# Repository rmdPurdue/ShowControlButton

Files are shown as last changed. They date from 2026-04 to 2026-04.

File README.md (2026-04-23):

# ShowControlButton
ShowControlButton is a simple, single-pushbutton controller in a box. Inside the box: a Feather M4 Express microcontroller, a relay breakout, an Ethernet breakout, and the capability to put a single pushbutton in your entertainment project and have it trigger a contact closure or trigger the contact closure and send a configurable OSC message to your show network.
## Easy to use
If you don't need OSC capabilities, set up is simple: supply power to the box using the Micro USB port on the back of the box, insert a 1/4" TS plug into the contact closure port and connect the other end to your footswitch device, MIDI footswitch controller, PLC input, or other device with a sourcing discrete input, up to 24V DC. BAM! Press the button, the contact closes for five seconds. Bonus: the 10mm diffused blue LED lights up when the contact is closed.

If you want OSC capabilities, the set up takes a few extra steps. You'll need to configure the network interface for your network, then configure the outgoing OSC message. Push the button: OSC message sent **and** contact closed!
## Network Configuration
The default network configuration for the ShowControlButton:

|Field|Setting|
|---|---|
|IP Address|192.168.1.100|
|Subnet Mask|255.255.255.0|
|Gateway|192.168.1.1|
|DNS Server|8.8.8.8|

To change the network settins for the ShowControlButton, connect the device to your laptop or computer with an Ethernet cable using the Ethernet port on the back of the box. Once connected, supply power using the Micro USB port on the back of the box. Ensure that the network interface on your laptop or computer is in the same address range and is using the same subnet mask as the ShowControl Button. Open a web browser and point it to the IP address of the ShowControlButton at port 5000 (e.g. http://192.168.1.100:5000).

> [!IMPORTANT]
> As of this writing, the ShowControlButton only detects a network connection at power up. If it is not connected to a network at power up, it will shut down the network interface and it will not detect the presence of a network later, even if one is connected, until power has been removed and resupplied. Future versions of the firmware should address this issue.

> [!TIP]
> "Uh oh! I changed my network settings at some point and I don't remember them. How do I access the network configuration web page?!" Easy: press and hold the reset button (located inside the small hole on the bottom of the box) for at least five seconds. This should restore the network configuration settings to the default settings. Connect your network cable, supply power, and point your web browser to http://192.168.1.100:5000 and you should be good to go!

## OSC Set up
Configuring the settings for the OSC message you wish to send when the ShowControlButton is pressed is as simple as navigating to the IP address of the device, just as when configuring the network settings. In the second form on the configuration page, you can set the message's destination IP address, the destination port, and the OSC message itself. As with any OSC message, use a blank space to separate any arguments from the address/method and from each other; the code will determine automatically if the argument is an integer, float, or string. Though we have not tested for large numbers of arguments, theoretically you should be able to store quite a few!

> [!IMPORTANT]
> The firmware will interpret any decimal value as a float: "1" is an integer, but "1.0" is a float. If the argument type **must** be an integer, don't include a ".0".

## Troubleshooting ##
The ShowControlButton software has not undergone robust stress testing; typically, if something goes wrong, remove power, count to ten, resupply power then try again. Restore to faculty defaults and reset your network configuration and OSC message configuration, if necessary.

## Parts List ##
- Adafruit Feather M4 Express (https://www.adafruit.com/product/3857)
- Adafruit Relay (Non-latching) Featherwing (https://www.adafruit.com/product/2895)
- Adafruit Ethernet Featherwing (https://www.adafruit.com/product/3201)
- 10mm Diffused Blue LED (https://www.adafruit.com/product/847)
- 10mm LED Bevel LED Holder (https://www.adafruit.com/product/2171)
- 12mm Tactile button (https://www.adafruit.com/product/1119)
- 22mm Plastic Button (white) (https://www.automationdirect.com/adc/shopping/catalog/pushbuttons_-z-_switches_-z-_indicators/pushbuttons/gcx3105)
- Micro USB extension (https://www.digikey.com/en/products/detail/adafruit-industries-llc/6068/25897272)
- Ethernet Coupler (https://www.mcmaster.com/catalog/3243T1)
- 1/4" TS Audio Jack (https://www.mcmaster.com/catalog/1760N21)
- Tactile Button mounting plate (3d printed) (https://github.com/rmdPurdue/ShowControlButton/blob/main/support%20files/Tactile%2BButton%2BMount.stp)
- Enclosure (including feet and standoffs, laser cut from 6mm draftboard) (https://github.com/rmdPurdue/ShowControlButton/tree/main/support%20files/laser-cut)

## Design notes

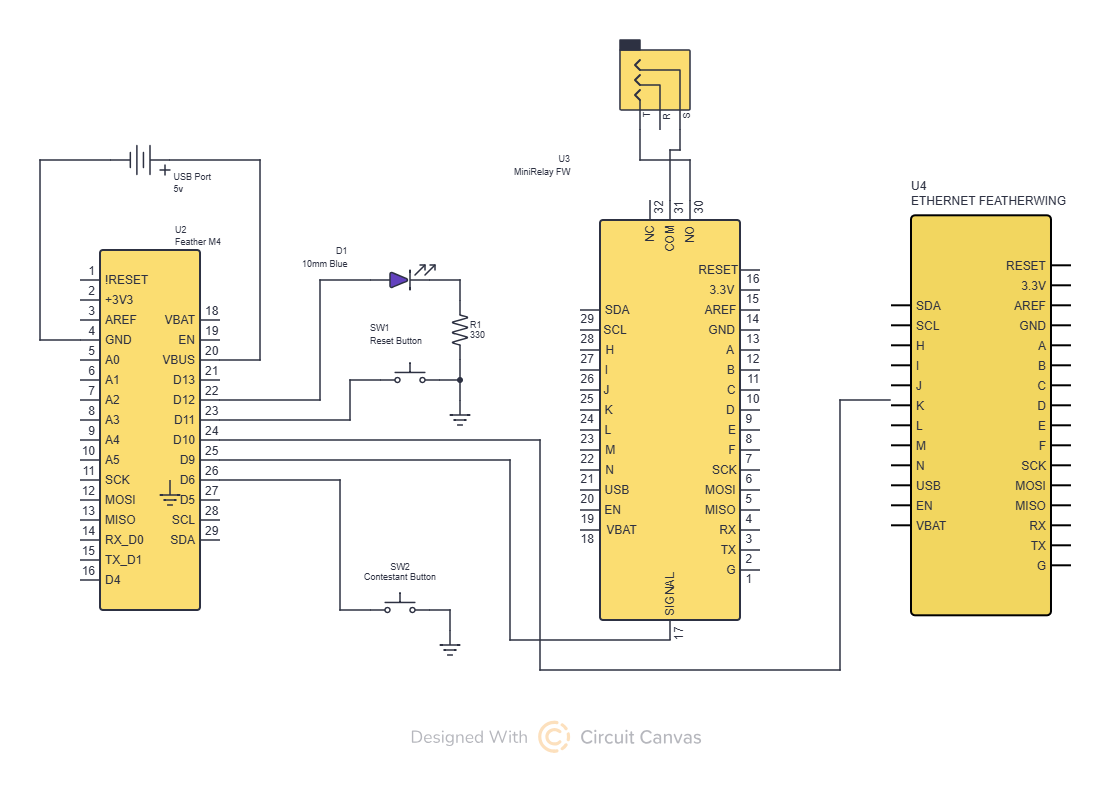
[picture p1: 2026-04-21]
support files/ShowControlButton-schematic.png

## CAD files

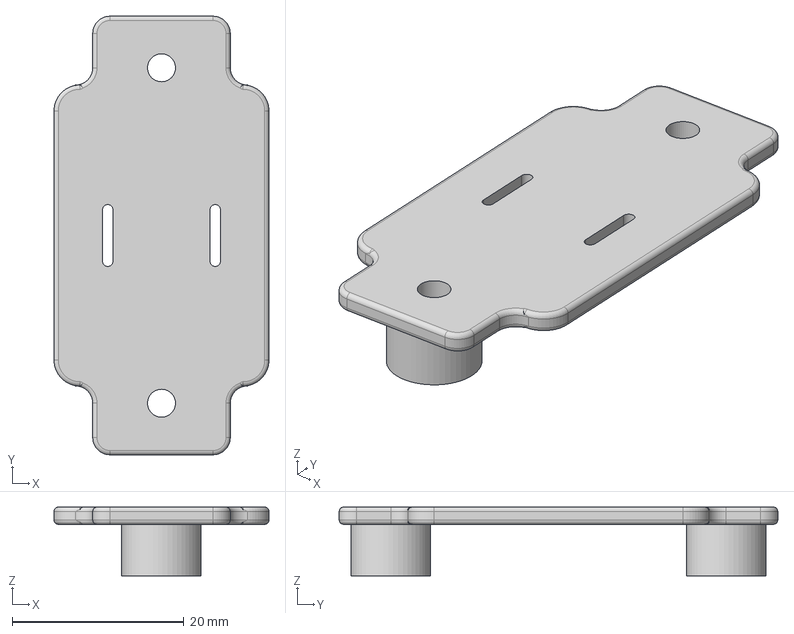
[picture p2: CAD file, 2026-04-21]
support files/Tactile+Button+Mount.stp
25.0 x 51.0 x 8.00 mm

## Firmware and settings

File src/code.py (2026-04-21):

import gc
import os

import adafruit_connection_manager
import board
import digitalio
import time
import microosc

from asyncio import create_task, gather, run
from asyncio import sleep as async_sleep
from adafruit_debouncer import Debouncer
from adafruit_wiznet5k.adafruit_wiznet5k import WIZNET5K

from adafruit_httpserver import (
    MIMETypes,
    POST,
    Response,
    REQUEST_HANDLED_RESPONSE_SENT,
    Request,
    Server,
)

from html import HTML_FORM
from network_config import NetworkConfig
from osc_message import OSCMessage

# Initialize contestant button
button_pin = digitalio.DigitalInOut(board.D6)
button_pin.direction = digitalio.Direction.INPUT
button_pin.pull = digitalio.Pull.UP
button = Debouncer(button_pin, interval=0.01)

# Initialize reset button
reset_pin = digitalio.DigitalInOut(board.D11)
reset_pin.direction = digitalio.Direction.INPUT
reset_pin.pull = digitalio.Pull.UP
reset = Debouncer(reset_pin, interval=0.01)

# Initialize contact closure output
contact = digitalio.DigitalInOut(board.D9)
contact.direction = digitalio.Direction.OUTPUT

# Initialize contact closure reset output for non-latching relay
contact_reset = digitalio.DigitalInOut(board.D13)
contact_reset.direction = digitalio.Direction.OUTPUT

# Initialize local led
led = digitalio.DigitalInOut(board.D12)
led.direction = digitalio.Direction.OUTPUT

# Default network config
my_network_config = NetworkConfig()
my_network_config.ip = os.getenv("IP")
my_network_config.subnet = os.getenv("SN")
my_network_config.gateway = os.getenv("GW")
my_network_config.dns = os.getenv("DNS")

# Initialize OSC message variable
osc_message = OSCMessage()
osc_message.destination = os.getenv("DIP")
osc_message.port = os.getenv("DP")
osc_message.payload(os.getenv("DM"))
if os.getenv("EN") == "True":
    osc_message.state = True
elif os.getenv("EN") == "False":
    osc_message.state = False

# For Adafruit Ethernet FeatherWing
cs = digitalio.DigitalInOut(board.D10)
spi_bus = board.SPI()

# Initialize ethernet interface without DHCP
eth = WIZNET5K(spi_bus, cs, is_dhcp=False)

eth.ifconfig = (my_network_config.ip,
                my_network_config.subnet,
                my_network_config.gateway,
                my_network_config.dns)

MIMETypes.configure(
    default_to="text/plain",
    keep_for=[".html", ".css", ".js", ".png", ".jpg", ".jpeg", ".gif", ".ico"],
)

# Create a socket pool
pool = adafruit_connection_manager.get_radio_socketpool(eth)
server = Server(pool, "../static", debug=True)


@server.route("/")
def base(request: Request):
    checked_state = None
    if osc_message.state:
        checked_state = "checked"
    return Response(request,
                    HTML_FORM.format(
                        network="display:none;",
                        osc="display:none;",
                        checked=checked_state,
                        ip=my_network_config.ip_as_string(),
                        subnet=my_network_config.subnet_as_string(),
                        gateway=my_network_config.gateway_as_string(),
                        dns=my_network_config.dns_as_string(),
                        destinationIP=osc_message.destination,
                        destinationPort=osc_message.port,
                        message=osc_message.payload_no_types()
                    ),
                    content_type="text/html", )


@server.route("/submit-network", POST)
def submit_form_handler(request: Request):
    # Parse form data from the POST request
    form_data = request.form_data
    my_network_config.ip = form_data.get("ip")
    my_network_config.subnet = form_data.get("subnet")
    my_network_config.gateway = form_data.get("gateway")
    my_network_config.dns = form_data.get("dns")
    checked_state = None
    if osc_message.state:
        checked_state = "checked"
    update_toml()
    gc.collect()
    # We have to restart the network connection here!

    return Response(request,
                    HTML_FORM.format(
                        network="display:inline;",
                        osc="display:none;",
                        checked=checked_state,
                        ip=my_network_config.ip_as_string(),
                        subnet=my_network_config.subnet_as_string(),
                        gateway=my_network_config.gateway_as_string(),
                        dns=my_network_config.dns_as_string(),
                        destinationIP=osc_message.destination,
                        destinationPort=osc_message.port,
                        message=osc_message.payload_no_types()
                    ),
                    content_type="text/html", )


@server.route("/submit-osc", POST)
def submit_form_handler(request: Request):
    # Parse form data from the POST request
    form_data = request.form_data
    osc_message.destination = form_data.get("destIp")
    osc_message.port = form_data.get("destPort")
    osc_message.payload(form_data.get("message"))
    if form_data.get("sendOSC") == "on":
        osc_message.state = True
    else:
        osc_message.state = False
    checked_state = None
    if osc_message.state:
        checked_state = "checked"
    update_toml()
    gc.collect()

    return Response(request,
                    HTML_FORM.format(
                        network="display:none;",
                        osc="display:inline;",
                        checked=checked_state,
                        ip=my_network_config.ip_as_string(),
                        subnet=my_network_config.subnet_as_string(),
                        gateway=my_network_config.gateway_as_string(),
                        dns=my_network_config.dns_as_string(),
                        destinationIP=osc_message.destination,
                        destinationPort=osc_message.port,
                        message=osc_message.payload_no_types()
                    ),
                    content_type="text/html", )


def update_toml():
    with open("settings.toml", "w") as f:
        f.write(f'IP = "{my_network_config.ip_as_string()}"\n')
        f.write(f'SN = "{my_network_config.subnet_as_string()}"\n')
        f.write(f'GW = "{my_network_config.gateway_as_string()}"\n')
        f.write(f'DNS = "{my_network_config.dns_as_string()}"\n')
        f.write(f'DIP = "{osc_message.destination}"\n')
        f.write(f'DP = "{osc_message.port}"\n')
        f.write(f'DM = "{osc_message.payload_no_types()}"\n')
        if osc_message.state:
            f.write('EN = "True"\n')
        else:
            f.write('EN = "False"\n')


# Start the server.
try:
    server.start(str(eth.pretty_ip(eth.ip_address)))
    my_network_config.disconnected = False
except Exception:
    my_network_config.disconnected = True
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

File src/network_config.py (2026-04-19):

class NetworkConfig:

    def __init__(self):
        self._ip = ()
        self._subnet = ()
        self._gateway = ()
        self._dns = ()
        self.disconnected = False

    @property
    def ip(self):
        return self._ip

    @ip.setter
    def ip(self, ip):
        self._ip = list(map(int, ip.split(".")))

    @property
    def subnet(self):
        return self._subnet

    @subnet.setter
    def subnet(self, subnet):
        self._subnet = list(map(int, subnet.split(".")))

    @property
    def gateway(self):
        return self._gateway

    @gateway.setter
    def gateway(self, gateway):
        self._gateway = list(map(int, gateway.split(".")))

    @property
    def dns(self):
        return self._dns

    @dns.setter
    def dns(self, dns):
        self._dns = list(map(int, dns.split(".")))

    def ip_as_string(self) -> str:
        return ".".join(map(str, self._ip))

    def subnet_as_string(self) -> str:
        return ".".join(map(str, self._subnet))

    def dns_as_string(self) -> str:
        return ".".join(map(str, self._dns))

    def gateway_as_string(self) -> str:
        return ".".join(map(str, self._gateway))

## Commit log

2026-04-21 Rename ShowControlButton-schematic.png to support files/ShowControlButton-schematic.png
2026-04-23 Rename support files/Back Side.svg to support files/laser-cut/Back Side.svg
2026-04-23 Rename support files/Bottom Side.svg to support files/laser-cut/Bottom Side.svg
2026-04-23 Rename support files/Foot and Stand Off.svg to support files/laser-cut/Foot and Stand Off.svg
2026-04-23 Rename support files/Front Side.svg to support files/laser-cut/Front Side.svg
2026-04-23 Rename support files/Left Side.svg to support files/laser-cut/Left Side.svg
2026-04-23 Rename support files/Right Side.svg to support files/laser-cut/Right Side.svg
2026-04-23 Rename support files/Top Side.svg to support files/laser-cut/Top Side.svg
